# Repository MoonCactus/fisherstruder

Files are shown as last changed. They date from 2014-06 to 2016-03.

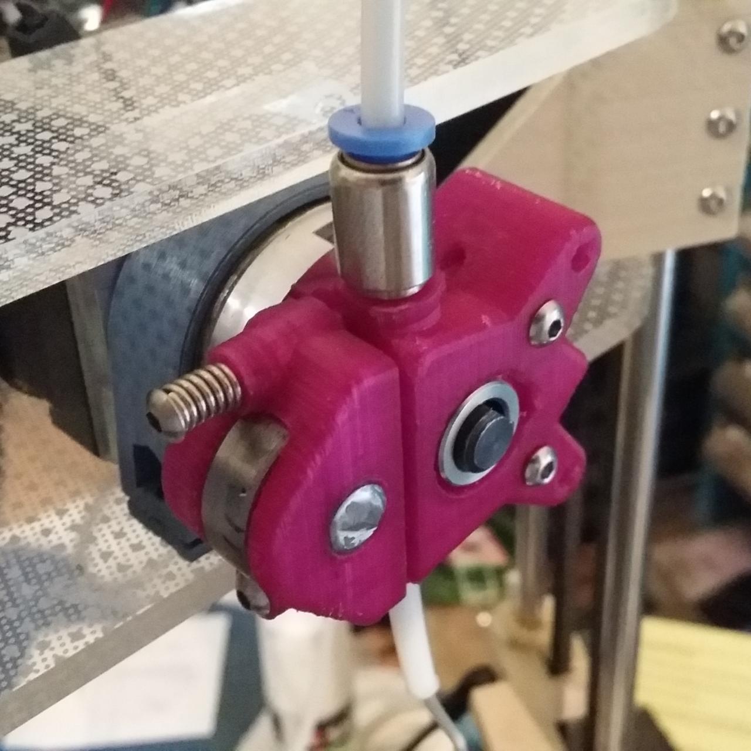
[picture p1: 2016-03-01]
fisherstruder.jpg

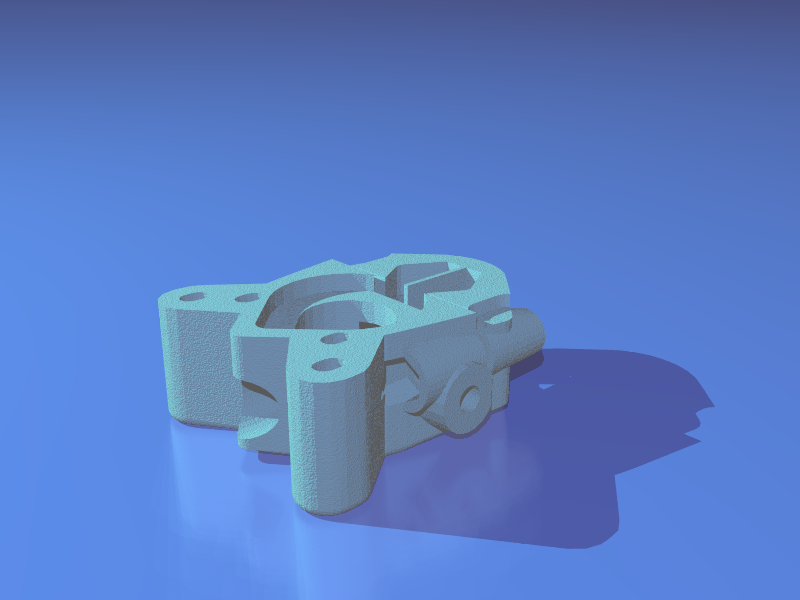
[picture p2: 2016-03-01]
fs_all.png

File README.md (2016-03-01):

Fisherstruder - A 1.75mm compact filament feeder for 3D printers. Direct drive, and with a cheap 608 roller bearing.

It can be coupled on a Nema17 with or without a reductor.

Fails at high speeds (>150mm/s), but it probably comes from my cheap MK8 bolt.
Ah, and it is annoying like hell if/when you want to access the internal. I should try to add a butterfly nut to release the idler part. At least it prints very quickly and is extremely robust (I was able to flatten the filament completely -- which did not improve grip!)

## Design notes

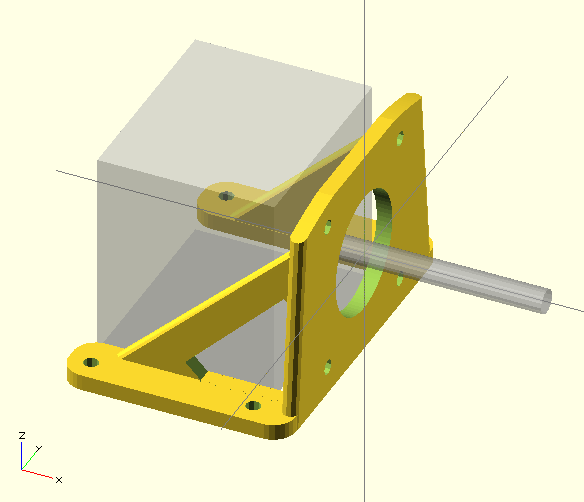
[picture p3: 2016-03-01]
nema17_stand.png

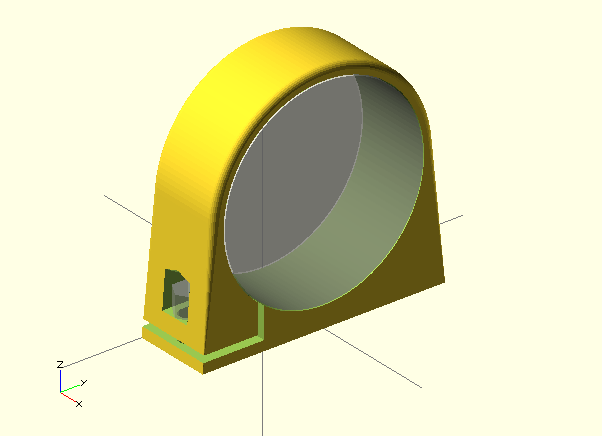
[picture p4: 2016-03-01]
nema17_reduc_holder.png

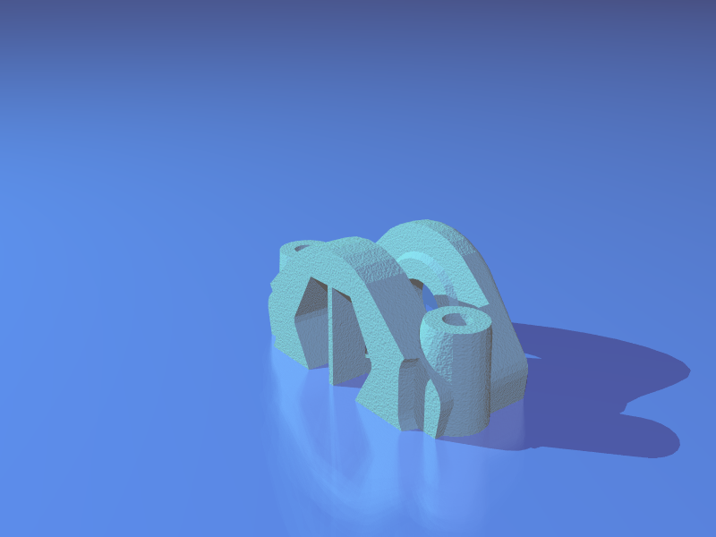
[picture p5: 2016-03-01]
fs_idler.png

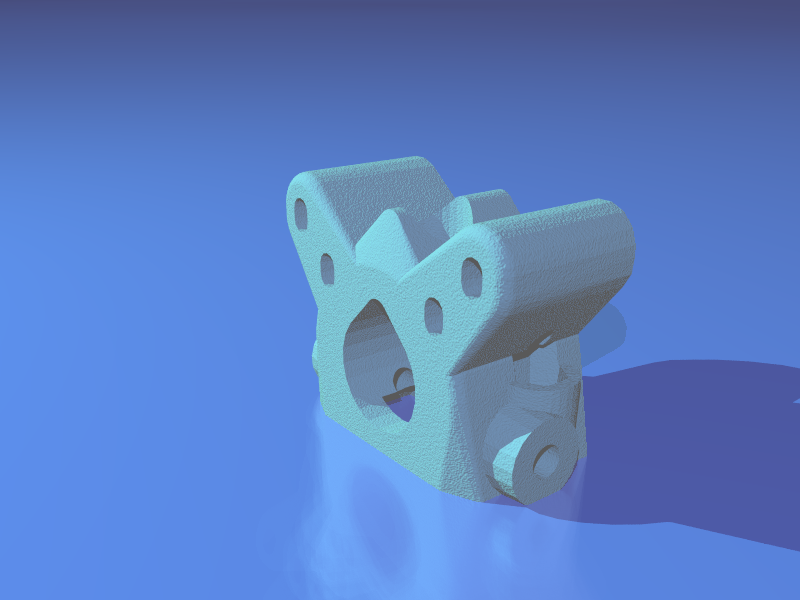
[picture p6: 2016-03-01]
fs_bolt.png

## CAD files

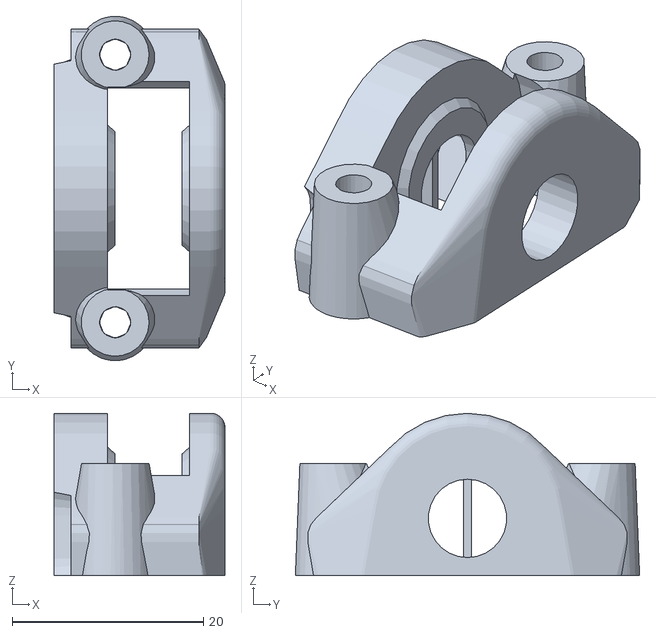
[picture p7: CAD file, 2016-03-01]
fs_idler.stl
17.9 x 36.0 x 17.0

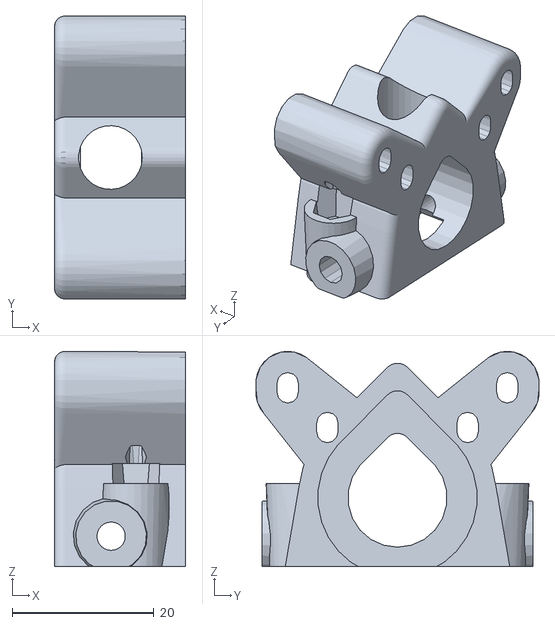
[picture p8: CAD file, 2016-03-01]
fs_body.stl
18.5 x 40.0 x 30.4

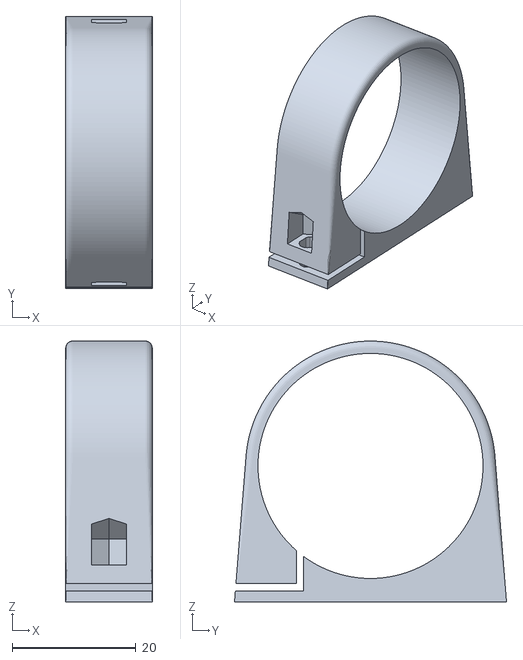
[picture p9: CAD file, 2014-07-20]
nema17_reduc_holder.stl
14.0 x 44.0 x 42.2

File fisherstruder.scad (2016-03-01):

// The fisherstruder - a compact 1.75mm filament extruder (direct drive with or without a nema 17 reductor)
// CC-BY-NC jeremie.francois at gmail.com July 2014

// Initially inspired by "Makergear Filament drive goes Bowden" by Luke321 at http://www.thingiverse.com/thing:63674

// Nb: I still think it sucks without quick release ;)

//include <../configuration.scad>;

// In bash:
// for w in all bolt idler; do openscad fisherstruder.scad -D "print_what=\"$w\"" -o fs_$w.stl; done

print_what="all";
//print_what="bolt";
//print_what="idler";

use <nema17_stand.scad>;

module extruder_feeder_head(what="all")
{
	tol=0.1;

	brg_608_th=7; 
	brg_608_outer_d=22; 
	brg_608_inner_d=8; 
	brg_608_shoulder_d= 8/2 + 2;

	m3_d= 3;
	m3_nut_d= 6;
	m3_head_d= 5.5;
	m3_head_h= 2.2;
	m8_nut_d= 14.6;
	m8_nut_h= 5.5 + 0.1;
	m3_nylock_h= 3.8;

	nema_head_indentation_depth= 2 + 0.8;
	nema_head_indentation_d= 22.5;
	nema_tune_offset= 1.3; // how oblong are the stepper mount holes
	
	hobbed_bolt_d= 12.5;
	hobbed_bolt_h= 11;
	hobbed_bolt_xd= hobbed_bolt_d + 1.5;

	slit_depth= 1.5; // how much the idle can be squeezed further against the filament
	slit_offset_x= 10.5; // where to slice the object (inside)
	slit_offset_depth= 0.6; // how much to shave on top on the idler

	idler_brg_wall_th= 5; // how thick is the wall around the idler axis
	idler_freeplay= 0.8; // space around the idler bearing
	idler_hscrew_extent= 22.9;
	idler_hscrew_start= -2;

	ear_d= m3_d + 6; // diameter of the stepper screw columns

	// we removed the 3mm thickness of the stepper mount wall!
	extruder_height= 21.5 - 3;
	
	filament_offset_z= 8;
	filament_offset_x= hobbed_bolt_d/2 - 0.8;

	// Bowden and pneufit related settings
	bowden_od=4;
	pneufit_support_length= 14;
	pneufit_screw_diameter= 4.6; // 5mm screw diameter
	pneufit_shoulder_diameter= 10;
	pneufit_shoulder_protrude= 0; // additional protrusion may be useful for some

	/*
	// Settings for a pneufit that would be 10mm long and 10mm screw diameter (eg. defaut E3D)
	pneufit_support_length= 14 + 2;
	pneufit_screw_diameter= 4.6*0 + 9;
	pneufit_shoulder_diameter= 10 + 4;
	pneufit_shoulder_protrude= 0 + 10; // additional protrusion may be useful for some
	*/
	
	// Overall roundness
	roundness= 3;
	
	// Computed values

	idler_eccentricity_x= brg_608_outer_d/2 + hobbed_bolt_d/2;
	idler_ear_offset_x= idler_eccentricity_x - 2;
	idler_ear_offset_y= brg_608_outer_d/2 + 3;
	idler_hscrew_y= brg_608_outer_d/2 + m3_d/2 + 1.5;
	idler_hscrew_z= filament_offset_z + bowden_od/2 + m3_d/2;

	// Printing support
	prn_help_nut_head_th=0.8;

	// Generic modules
	module torus(r,rnd)
	{
		translate([0,0,rnd/2])
			rotate_extrude($fs=0.8)
				translate([r-rnd/2, 0, 0])
					circle(r= rnd/2, $fs=0.2);
	}

	module rtower(r, h=extruder_height)
	{
		hull()
		{
			torus(r=r, rnd= roundness);
			translate([0,0,r])
				cylinder(r=r, h= h-r);
		}
	}

	module drop(r, offset=tol, h=extruder_height, rounded_top=false)
	{
		translate([0,0,-offset])
			hull()
		{
			if(rounded_top)
			{
				rtower(r=r, h= h+2*offset);
				translate([-(r-2)*1.414,0,0])
					rtower(r=2, h=h+2*offset, $fs=0.5);
			}
			else
			{
				cylinder(r=r, h= h+2*offset);
				translate([-(r-2)*1.414,0,0])
					cylinder(r=2, h=h+2*offset, $fs=0.5);
			}
		}
	}

	// The RM extruder
	module nema_screws(dx, dy, carve=false)
	{
		translate([dx*31/2,dy*31/2,carve?-tol:0])
			for (a = [0:$children-1])
				child(a);

		// Second set of mount positions for reductor-equipped nema motors
		if(dx<0)
			translate([dx*28/(1.414*2),dy*28/(1.414*2),carve?-tol:0])
				for (a = [0:$children-1])
					child(a);
				
	}

	module hex_nut_carve()
	{
		rotate([0,0,30])
			cylinder(r=m8_nut_d/2 + 0.3,h=m8_nut_h+2*tol, $fn=6);
	}

	module nema_carve()
	{
		//gearhead indentation
		translate([0,0,extruder_height-nema_head_indentation_depth+tol])
			drop(h=nema_head_indentation_depth, r=nema_head_indentation_d/2);

		// mounting holes (twice, so that it is compatible with NEMA 17 and planetary gearbox)
		for(y=[-1,+1])
		{
			nema_screws(dx=-1, dy=y, carve=true)
			{
				hull()
					for(x=[-1,+1])
						translate([x*nema_tune_offset/2,0,0])
							cylinder(r=m3_d/2, h= extruder_height + 2*tol, $fn=12);
			}

			// Carve also pockets for the heads of the two other
			// M3 stepper screws (these only hold the stepper).
			nema_screws(dx=+1, dy=y, carve=true)
				hull() for(dx=[-1,+1])
					translate([dx*(slit_depth/2 + nema_tune_offset + 0.2),0,extruder_height-m3_head_h-0.1])
						cylinder(r1=m3_head_d/2+0.1, r2=m3_head_d/2+0.8, h= m3_head_h + 0.1+2*tol, $fs=1);
		}
	}
	
	module idler_axis_carve()
	{
		// M8 bearing axis, and the hexagonal nut head
		translate([idler_eccentricity_x,0,-tol])
		{
			cylinder(r=brg_608_inner_d/2 + 0.1, h=extruder_height-(m8_nut_h)+2*tol, $fs=1);
			translate([0, 0, extruder_height-m8_nut_h])
			{
				difference()
				{
					hull() for(dx=[-1,0])
						translate([dx*(slit_depth/2+0.1),0,0])
							hex_nut_carve();
					if(prn_help_nut_head_th>0) // helps printing the nut overhang
						translate([-m8_nut_d/2,-prn_help_nut_head_th/2,0.3])
							cube([m8_nut_d,prn_help_nut_head_th,m8_nut_h+tol]);
				}
			}
		}
	}

	module hobbed_bolt_carve()
	{
		drop(r=hobbed_bolt_xd/2);
		%translate([0,0,filament_offset_z]) difference()
		{
			// position and diameter of the internal hobbed bolt groove
			cylinder(r=10.65/2,h=0.4,center=true);
		}
	}

	module tight_hscrew()
	{
		for(y=[-1,+1])
			scale([1,y,1])
				translate([0, idler_hscrew_y, idler_hscrew_z])
					rotate([0,90,0])
						for (a = [0:$children-1])
							child(a);
	}

	difference()
	{
		// Body
		union()
		{
			// Positive shape
			hull()
			{
				// Central body
				drop(r=28/2, offset=0, rounded_top=true);

				// Protruding junction to the idler bearing axis
				translate([idler_eccentricity_x,0,0]) // body around the bearing axis
					rtower(r=brg_608_inner_d/2 + idler_brg_wall_th + 2);

				// ears around the idler bearing
				for(y=[-1,1])
					translate([idler_ear_offset_x, y*idler_ear_offset_y, 0])
						rtower(r=m3_head_d/2, $fs=1);
			}
			
			// Ears (stepper atachment holes)
			for(y=[-1,+1]) hull()
			{
				cylinder(r=15/2, h= extruder_height);
				nema_screws(dx=-1, dy=y)
					hull()
					for(x=[-1,+1])
						translate([x*nema_tune_offset/2,0,0])
							rtower(ear_d/2);
			}

			// Cylindrical lateral bodies for the idler tightening screws
			tight_hscrew()
			{
					hull()
					{
						translate([0,0,idler_hscrew_extent])
						{
							translate([0,-3,-(idler_hscrew_extent-idler_hscrew_start)/2]) cylinder(r=m3_head_d/2 + 3, h=tol);
							cylinder(r= m3_head_d/2 + 0.8, h=tol, $fs=1);
						}
						// Thightener head (inside)
						translate([0, 0, idler_hscrew_start]) cylinder(r=m3_head_d/2 + 1.8 , h=tol, $fs=1);
					}
			}

			// Side flats for the the pushfit connector and bowden output
			intersection()
			{
				for(y=[-1,1]) scale([1,y,1]) // y>0 for the output side
				translate([filament_offset_x, 0, filament_offset_z])
					rotate([-90,0,0])
						translate([0, 0, pneufit_support_length-6])
							cylinder(r1=pneufit_shoulder_diameter/2+1, r2=pneufit_shoulder_diameter/2, h= 6 + 5 + tol + (y>0 ? pneufit_shoulder_protrude : 0));
				translate([0,0,extruder_height/2]) cube([60,60,extruder_height], center = true); // chop anything that protrudes top & bottom
			}
		}
		
		// Negative shapes now on

		// Carve filament passage
		translate([filament_offset_x, 0, filament_offset_z])
			rotate([-90,0,0])
		{
				cylinder(r=bowden_od/2, h=100, center = true, $fs=0.5);
				//pushfit/pneufit mount
				translate([0, 0, pneufit_support_length])
					cylinder(r=pneufit_screw_diameter/2, h=5+2*tol + pneufit_shoulder_protrude, $fn=12);
		}

		// Carve the horizontal screw that tightens the idler
		tight_hscrew()
		{
			// nylock slot
			translate([0, 0, - m3_nylock_h + idler_hscrew_start + 1])
				cylinder(r1=m3_nut_d/2+0.8, r2=m3_nut_d/2-0.1, h=m3_nylock_h + 2, $fn=6);

			hull()
			{
				translate([0, 0, -10.5]) cylinder(h=tol, r=m3_d/2-0.1, $fn=6);
				cylinder(h=tol, r=m3_d/2+0.1, $fn=8);
				translate([0, 0, 31.5]) cylinder(h=tol, r=m3_d/2 + 0.15, $fs=0.5); // the diameter on the idler side is a bit larger
			}
		}

		// side opening for the idler bearing
		translate([idler_eccentricity_x,0,filament_offset_z])
		{
			difference()
			{
				hull()
				{
					for(x=[-1,+1])
						translate([x*slit_depth/2,0,0])
							cylinder(r= brg_608_outer_d/2 + idler_freeplay, h=brg_608_th + 2*idler_freeplay, center = true);
				}
				for(y=[-1,+1]) scale([1,1,-1])
					translate([slit_depth/2,0,y*(brg_608_th/2)])
						scale([1,1,y])
							cylinder(r1= brg_608_shoulder_d, r2= brg_608_shoulder_d+ idler_freeplay, h=idler_freeplay+tol);
			}
			%cylinder(r= brg_608_outer_d/2, h=brg_608_th, center = true); // bearing ghost
		}
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

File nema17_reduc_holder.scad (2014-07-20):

// Ring holder for a nema17 reductor
// E.g.: http://www.omc-stepperonline.com/gear-ratio-51-planetary-gearbox-with-nema-17-bipolar-stepper-17hs151684spg5-p-143.html
// CC-BY-NC jeremie.francois at gmail.com July 2014
// Use two M3 16 mm screws when your support is 6 mm thick

tol= 0.05;
reduc_d= 36;
reduc_d_tol= 0.4;
wall_d_th= 2.2;
reduc_len= 14; // 23 max
nema_side_len= 42+2; // nema side len (minimum 42)
slit_th=1.2;

m3= 3;
m3_len= 8;
base_th1= 1.8;
base_th2= 3;

rounding=2.2;

dist_b_screws= nema_side_len-7;

m3_d= 3;
m3_nut_d= 6;
m3_nut_dtol= 0.3;
m3_head_d= 5.5;
m3_head_h= 2.2;
m3_nylock_h= 3.8;

$fa=1;
$fs=1;

module torus(r,rnd)
{
	translate([0,0,rnd/2])
		rotate_extrude($fs=0.8)
			translate([r-rnd/2, 0, 0])
				circle(r= rnd/2, $fs=0.3);
}


module ring_body()
{
	difference()
	{
		hull()
		{
			translate([0,-nema_side_len/2,0]) cube([reduc_len, nema_side_len, tol]);
			translate([0,0,reduc_d/2 + (nema_side_len-reduc_d)/2])
				rotate([0,90,0])
					hull()
				{
					torus(r= reduc_d/2 + wall_d_th, rnd=rounding);
					translate([0,0,reduc_len-rounding])
						torus(r= reduc_d/2 + wall_d_th, rnd=rounding);
				}
		}
		
		translate([-tol,0,reduc_d/2 + (nema_side_len-reduc_d)/2])
			rotate([0,90,0])
			{
				%cylinder(r= reduc_d/2, h= reduc_len + 2*tol);
				cylinder(r= reduc_d/2 + reduc_d_tol/2, h= reduc_len + 2*tol);
			}

		// Holes for the attachment screws
		for(y=[-1,+1]) scale([1,y,1])
		{
			translate([reduc_len/2, dist_b_screws/2, 0])
			{
				if(y>0)
					translate([0,0,-tol]) cylinder(r=m3/2, h=m3_len);
				else
				{
					// onblong hole for the nylock
					translate([0,0,-tol])
					hull()
					for(sdy=[-1,+1]) scale([1,sdy,1]) translate([0,0.6,0])
					{
						cylinder(r=m3/2+0.1, h=m3_len, $fs=0.8);
					}
				}
				translate([0,0,base_th1+base_th2+slit_th]) hull()
				{
					% rotate([0,0,30]) cylinder(r=m3_nut_d/2, h=m3_nylock_h, $fn=6); // nylock ghost
					for(dy=[0,1])
						translate([0,dy*5,0])
							hull()
							{
								rotate([0,0,30]) cylinder(r=m3_nut_d/2+m3_nut_dtol, h=m3_nylock_h+0.4, $fn=6);
								translate([0,8,0])
									rotate([0,0,30]) cylinder(r=m3_nut_d/2+m3_nut_dtol, h=m3_nylock_h+5, $fn=6);
							}
				}
			}
		}

		// Slit on one side
		hull()
		{
			translate([-tol,-nema_side_len/2 + 10, base_th1]) cube([reduc_len+2*tol,slit_th,slit_th]);
			translate([-tol,-nema_side_len/2 + 10, 10]) cube([reduc_len+2*tol,slit_th,slit_th]);
		}
		hull()
		{
			translate([-tol,-nema_side_len/2 + 10, base_th1]) cube([reduc_len+2*tol,slit_th,slit_th]);
			translate([-tol,-nema_side_len/2 - 10, base_th1]) cube([reduc_len+2*tol,slit_th,slit_th]);
		}
		
	}
}


ring_body();

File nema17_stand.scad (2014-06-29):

//============================================================================== MOTOR PLATE



module extruder_mount()
{
	tol=0.1;
	$fa=0.1;
	$fs=1;


	csth= 3.2; // wall and bottom thickness
	csm= 3; // margin around plate holes

	space_below_stepper= 0.15; //-// csth+0.15

	motor_side= 42;
	motor_axis_z= csth + motor_side/2;

	motor_shaft_d= 5 - 0.2;
	m3_d= 3;

	motor_height= 35.4;
	motor_diag_screws= 46.5 - 2.7;

	plate_len= motor_height + 4;
	arm_reduced_h= 3;


	module tolz()
	{
		translate([0,0,-tol]) child(0);
	}


	module debug_motor()
	{
		%translate([-1,-motor_side/2,space_below_stepper])
		{
			cube([motor_height, motor_side, motor_side]);
			translate([0,motor_side/2,motor_side/2]) rotate([0,90,0]) cylinder(r=motor_shaft_d/2,h=80);
		}
	}

	module base_holes(inner_delta_x=0, inner_delta_y=0)
	{
		for(y=[-1,+1])
			for(x=[-1,+1])
				translate([x*(plate_len/2 - csm/2 - inner_delta_x-2) - 2,y*(29 - inner_delta_y),0])
					for (a = [0:$children-1]) child(a);
	}

	module motor_walls()
	{
		for(y=[-1,+1])
			translate([-plate_len/2,y*(motor_side/2 + csth),0])
					translate([arm_reduced_h,0,0])
				difference()
				{
					hull()
					{
						cylinder(r=csth/2, h=tol);
						translate([plate_len+csth/2-arm_reduced_h,0,0]) cylinder(r=csth/2 - 0.1, h=plate_len-arm_reduced_h);
					}
					// lateral holes
					translate([plate_len*0.9,-tol,motor_side*0.15]) rotate([-90,0,0]) cylinder(r=plate_len*0.5,h=csth+4*tol,center=true, $fn=4);
				}
	}

	translate([-plate_len/2 - csth, 0, -motor_side/2 - space_below_stepper]) // centered the view on the motor shaft
	{

		// Bottom
		difference()
		{
			union()
			{
				//-// hull() base_holes() cylinder(r=m3_d/2+csm,h=csth);
				for(y=[-1,+1])
					hull()
						for(x=[-1,+1])
							translate([x*(plate_len/2 - csm/2),y*(29),0])
								for (a = [0:$children-1]) { cylinder(r=m3_d/2+csm,h=csth); translate([0,-y*2,0]) cylinder(r=m3_d/2+csm,h=csth); }

				motor_walls();
			}
			// Remove screw holes
			base_holes() tolz() cylinder(r=m3_d/2,h=csth+2*tol);
			// And remove the central hole in the floor (faster print)
			//-//		hull() base_holes(inner_delta_x=8, inner_delta_y=11.8) tolz() cylinder(r=m3_d/2+csm,h=csth+2*tol);
		}

		// Mounting wall
		translate([plate_len/2+csm/2,0,0])
			intersection()
			{
				// Front wall
				translate([0,0,space_below_stepper])
				difference()
				{
					difference()
					{
						// Front wall between the two outer columns
						hull()
							for(y=[-1,+1])
								translate([0, y*(motor_side/2 + csth ), -space_below_stepper])
									hull()
									{
										translate([0,y*4,0]) cylinder(r=csth/2, h=tol); // corners
										translate([0, 0, motor_side]) cylinder(r=csth/2, h=tol);
									}
						translate([0,0,motor_side/2])
						{
							// Motor axis shoulder
							rotate([0,90,0]) cylinder(r=22.3/2+1,h= csth+2*tol, center=true);
							// Motor holes
							for(r=[0:90:359])
								rotate([0,90,0])
									rotate([0,0,r+45])
										translate([0,motor_diag_screws/2,0])
											cylinder(r=m3_d/2, h=csth*2+2*tol, center=true);
						}
					}
				}
				union() // cosmetic round top :p
				{
					hull() for(z=[0,26]) translate([-csth,0,z+space_below_stepper]) scale([1,1,0.4]) rotate([0,90,0]) cylinder(r=motor_side, h=csth*3);
				}
			}

		%translate([-plate_len/2,0,0]) debug_motor();
	}

}

//============================================================================== ALL COMPONENTS

extruder_mount();

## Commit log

2014-06-29 initial upload
    [fisherstruder.scad, nema17_stand.scad]
2014-07-17 Detailed pneufit settings
    [fisherstruder.scad]
2014-07-17 Added bash line to generate the parts
    [fisherstruder.scad]
2014-07-20 Added holder for the reductor-equipped version
    [nema17_reduc_holder.scad, nema17_reduc_holder.stl]
2014-07-20 tweaked for better tolerance when printed
    [nema17_reduc_holder.scad, nema17_reduc_holder.stl]
2014-07-20 Doc and final tweaks
    [nema17_reduc_holder.scad]
2014-12-13 added stl files
    [fs_body.stl, fs_idler.stl]
2015-02-11 Added real world picture
    [fisherstruder.scad, fs_idler.stl]
